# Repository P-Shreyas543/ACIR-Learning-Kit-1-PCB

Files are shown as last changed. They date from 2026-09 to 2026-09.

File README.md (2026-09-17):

# ACIR Learning Kits - Characterization & Experimentation Platform

**Decibels Lab Pvt Ltd**  
*Project Repository: [ACIR-Learning-Kit-1-PCB](https://github.com/P-Shreyas543/ACIR-Learning-Kit-1-PCB)*  
*Revision: v2.1 | Date: 2026-09-17*

---

## Overview

The **ACIR Learning Kits** are specialized, production-ready hardware characterization platforms designed for educational, research, and laboratory electrochemical impedance spectroscopy (EIS) and AC internal resistance (ACIR) testing of 18650 lithium-ion cells.

The repository contains two distinct learning kits:

### Learning Kit 1: Baseline Cell & Pack Topology Kit
1. **1S 1P Baseline Cell**: Single 18650 cell baseline ACIR characterization.
2. **1S 4P Parallel Pack**: Four-cell parallel module for current-sharing, contact resistance, and parallel cell mismatch studies.
3. **4S 1P Series String**: Four-cell series string for cumulative pack impedance and inter-cell busbar resistance.

### Learning Kit 2: Track Resistance & Interconnect Impedance Kit
1. **PCB Track Resistance Module**:
   - 3 calibrated test tracks with identical $6.0\text{ mm}$ width and varying lengths ($104.4\text{ mm}$, $58.0\text{ mm}$, $36.4\text{ mm}$).
   - Mirrored symmetrically on both copper layers (`F.Cu` and `B.Cu`).
   - Densely stitched with regular via matrices ($0.8\text{ mm}$ diameter, $0.4\text{ mm}$ drill).
   - Dedicated Kelvin test point probes: `P1` & `P2` (Track 1), `P3` & `P4` (Track 2), `P5` & `P6` (Track 3).
2. **4S 1P - (I) Module (Differential Cell ACIR Experiment)**:
   - 4 series cells (`BT2`, `BT3`, `BT4`, `BT5`) with uniform, ultra-low resistance interconnect buses ($8.0\text{ mm}$ 2-layer with dense via arrays).
   - Pack terminals: `B +ve` (BT2) and `B -ve` (BT5).
   - Students insert cells with *different* known ACIR values to observe that total pack ACIR is dominated by the sum of individual cell ACIRs when bus resistances are identical and negligible.
3. **4S 1P - (II) Module (Varying Interconnect Impedance Experiment)**:
   - 4 series cells (`BT6`, `BT7`, `BT8`, `BT9`) with deliberately *varying* interconnect track resistances:
     - **Link 1** (`BT6` $\leftrightarrow$ `BT7`): Ultra-wide $10.0\text{ mm}$ 2-layer bus with dense via matrix ($\approx 0.5\text{ m}\Omega$).
     - **Link 2** (`BT7` $\leftrightarrow$ `BT8`): Medium $3.0\text{ mm}$ single-layer trace ($\approx 3.0\text{ m}\Omega$).
     - **Link 3** (`BT8` $\leftrightarrow$ `BT9`): Narrow $0.8\text{ mm}$ single-layer trace ($\approx 10.0\text{ m}\Omega$).
   - Pack terminals: `B +ve` (BT6) and `B -ve` (BT9).
   - Students insert cells with *identical* ACIR values to demonstrate how interconnect trace impedance directly inflates total battery pack ACIR.

---

## Repository Structure

```
c:/Users/Shreyas/Documents/ACIR_PCB/
├── README.md                                  # Workspace Platform Documentation
├── .gitignore                                 # Git Ignore Configuration
├── ACIR-Learning-Kit-1-PCB/                   # Learning Kit 1 Project Directory
│   ├── ACIR-Learning-Kit-1-PCB.kicad_pro      # KiCad 10 Project File
│   ├── ACIR-Learning-Kit-1-PCB.kicad_pcb      # 2-Layer PCB Layout File
│   ├── ACIR-Learning-Kit-1-PCB.kicad_sch      # Complete Schematic Design
│   ├── ACIR-Learning-Kit-1-PCB.kicad_prl      # User Settings & Display Cache
│   ├── ACIR-Learning-Kit-1-PCB_BOM.csv        # Bill of Materials
│   ├── ACIR-Learning-Kit-1-PCB_LAYOUT.pdf     # Vector Layout Drawing
│   ├── ACIR-Learning-Kit-1-PCB_SCH.pdf        # Vector Schematic Drawing
│   ├── ACIR-Learning-Kit-1-PCB-drc.rpt        # DRC Verification Report (0 violations)
│   ├── ACIR-Learning-Kit-1-PCB-erc.rpt        # ERC Verification Report (0 errors)
│   ├── fp-lib-table                           # Footprint Library Table
│   ├── footprints.pretty/                     # Project Footprint Library
│   ├── gerbers/                               # RS-274X Gerbers & Drill Files
│   └── production/                            # JLCPCB Fabrication Deliverables
│       ├── ACIR-Learning-Kit-1-PCB_gerbers.zip# Complete Fabrication Archive
│       ├── ACIR-Learning-Kit-1-PCB_LAYOUT.pdf # Layout Drawing PDF
│       ├── ACIR-Learning-Kit-1-PCB_SCH.pdf    # Schematic Drawing PDF
│       ├── bom.csv                            # Component BOM
│       ├── positions.csv                      # Centroid Component Placement
│       └── netlist.ipc                        # IPC-D-356 Test Netlist
│
└── ACIR-Learning-Kit-2-PCB/                   # Learning Kit 2 Project Directory
    ├── ACIR-Learning-Kit-2-PCB.kicad_pro      # KiCad 10 Project File
    ├── ACIR-Learning-Kit-2-PCB.kicad_pcb      # 2-Layer PCB Layout File
    ├── ACIR-Learning-Kit-2-PCB.kicad_sch      # Complete Schematic Design
    ├── ACIR-Learning-Kit-2-PCB.kicad_prl      # User Settings & Display Cache
    ├── ACIR-Learning-Kit-2-PCB_BOM.csv        # Bill of Materials
    ├── ACIR-Learning-Kit-2-PCB_LAYOUT.pdf     # Vector Layout Drawing
    ├── ACIR-Learning-Kit-2-PCB_SCH.pdf        # Vector Schematic Drawing
    ├── ACIR-Learning-Kit-2-PCB-drc.rpt        # DRC Verification Report (0 violations)
    ├── ACIR-Learning-Kit-2-PCB-erc.rpt        # ERC Verification Report (0 errors)
    ├── kit2_render_top.png                    # Photorealistic 3D Top Render
    ├── kit2_render_bottom.png                 # Photorealistic 3D Bottom Render
    ├── fp-lib-table                           # Footprint Library Table
    ├── footprints.pretty/                     # Project Footprint Library
    ├── gerbers/                               # RS-274X Gerbers & Drill Files
    └── production/                            # JLCPCB Fabrication Deliverables
        ├── ACIR-Learning-Kit-2-PCB_gerbers.zip# Complete Fabrication Archive
        ├── ACIR-Learning-Kit-2-PCB_LAYOUT.pdf # Layout Drawing PDF
        ├── ACIR-Learning-Kit-2-PCB_SCH.pdf    # Schematic Drawing PDF
        ├── bom.csv                            # Component BOM
        ├── positions.csv                      # Centroid Component Placement
        └── netlist.ipc                        # IPC-D-356 Test Netlist
```

---

## PCB Specifications (Both Kits)

- **Dimensions**: $297.0\text{ mm} \times 210.0\text{ mm}$ (Standard A4 Landscape)
- **Layer Count**: 2 Layers ($1\text{ oz}$ / $35\,\mu\text{m}$ copper per layer)
- **Board Thickness**: $1.6\text{ mm}$ FR-4
- **Surface Finish**: HASL / ENIG compatible
- **Fabrication Compliance**: Verified 100% compliant with JLCPCB 2-layer fabrication capabilities:
  - **DRC**: **0 violations**, **0 unconnected pads**
  - **ERC**: **0 violations**, **0 errors**, **0 warnings**

---

## Design Team
- **Ashutosh Raj**
- **Shreyas P**
- **Suraj S D**

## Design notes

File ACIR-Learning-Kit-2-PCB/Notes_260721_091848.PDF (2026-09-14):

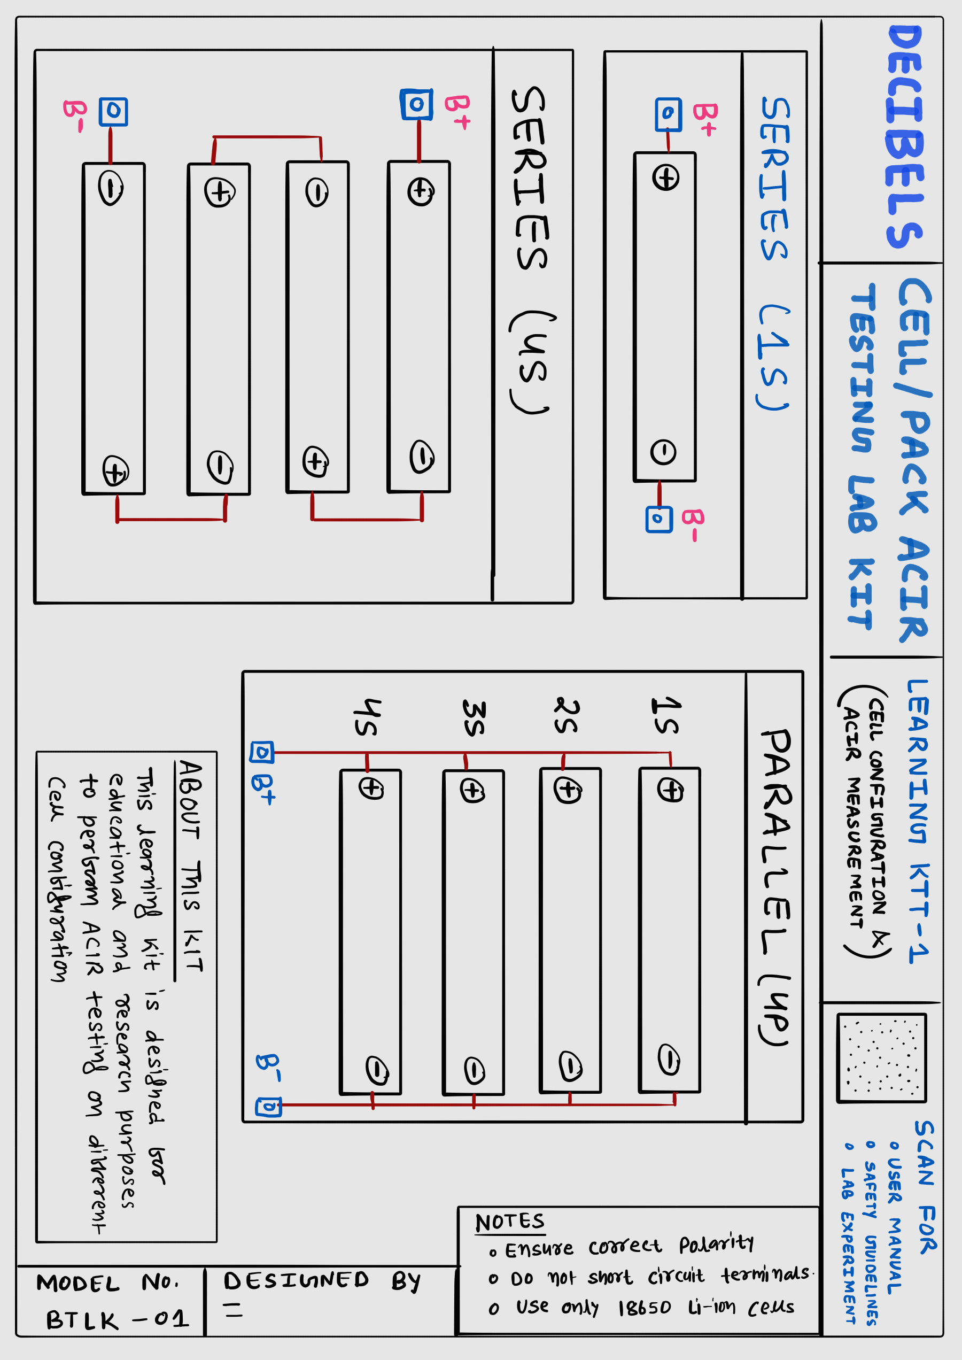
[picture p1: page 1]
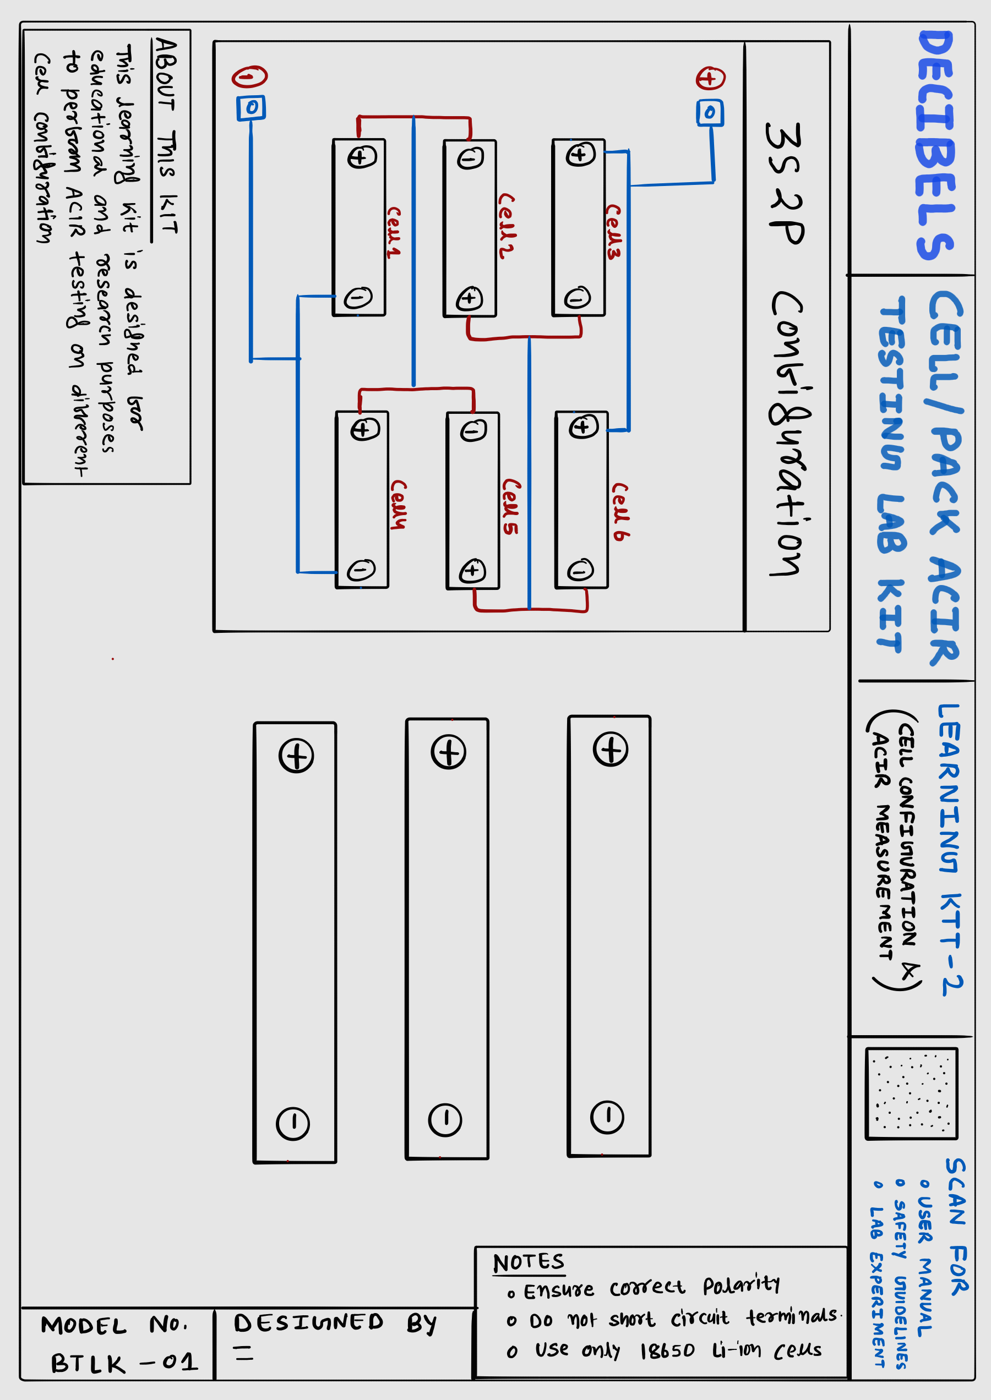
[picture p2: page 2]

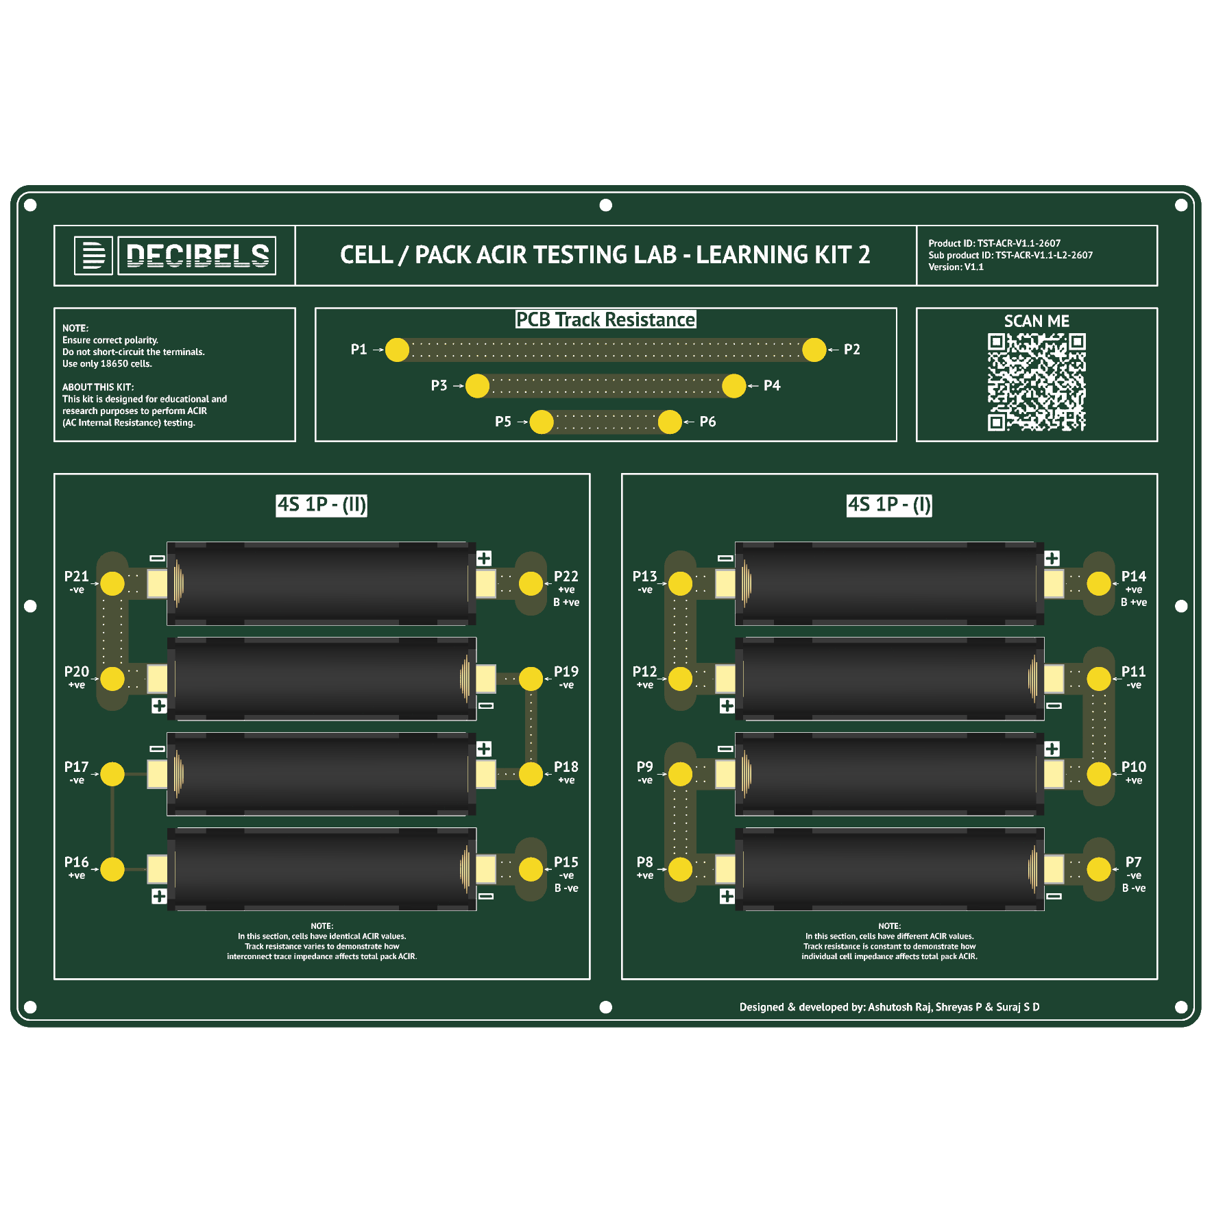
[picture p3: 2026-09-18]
ACIR-Learning-Kit-2-PCB/kit2_render_top.png

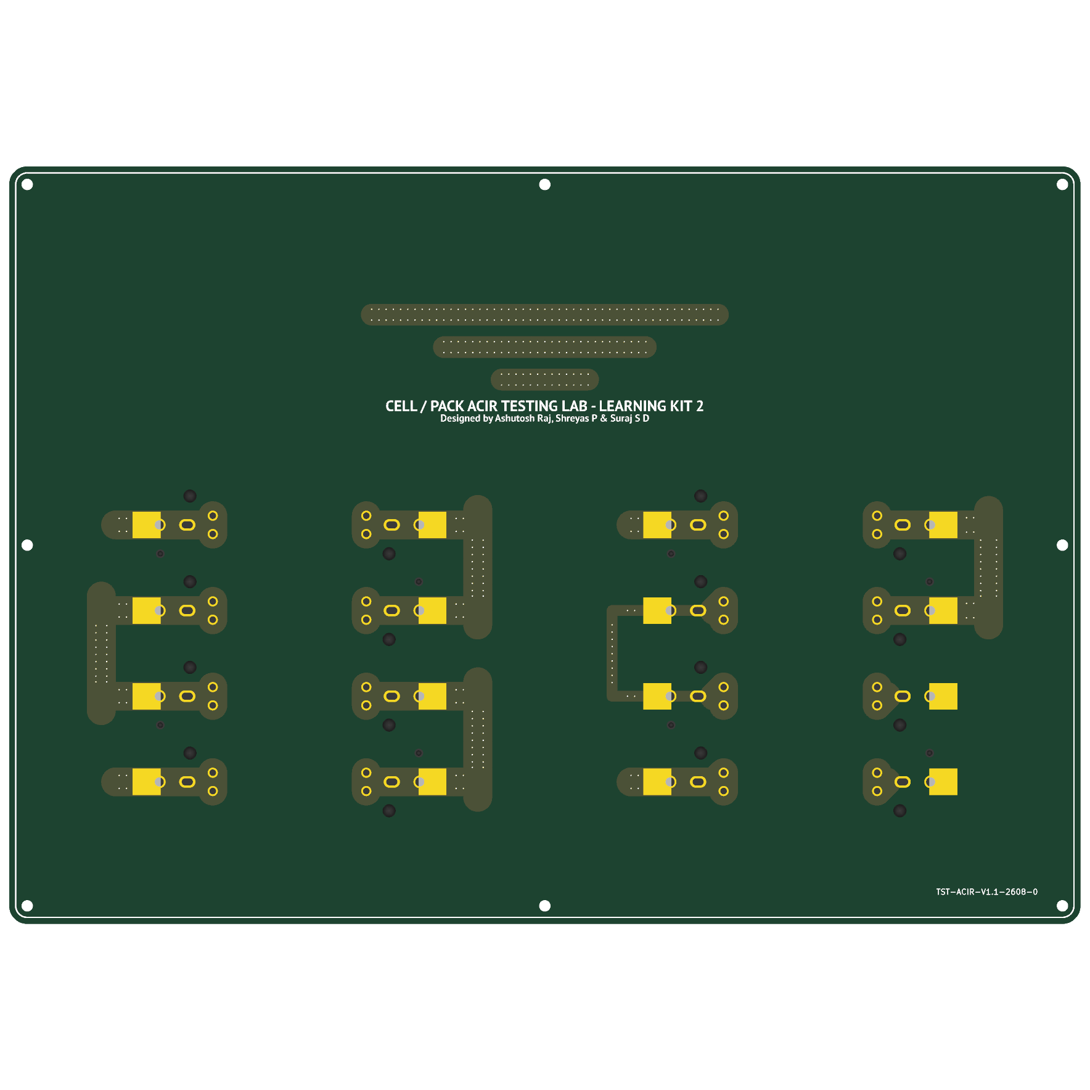
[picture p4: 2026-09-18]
ACIR-Learning-Kit-2-PCB/kit2_render_bottom.png

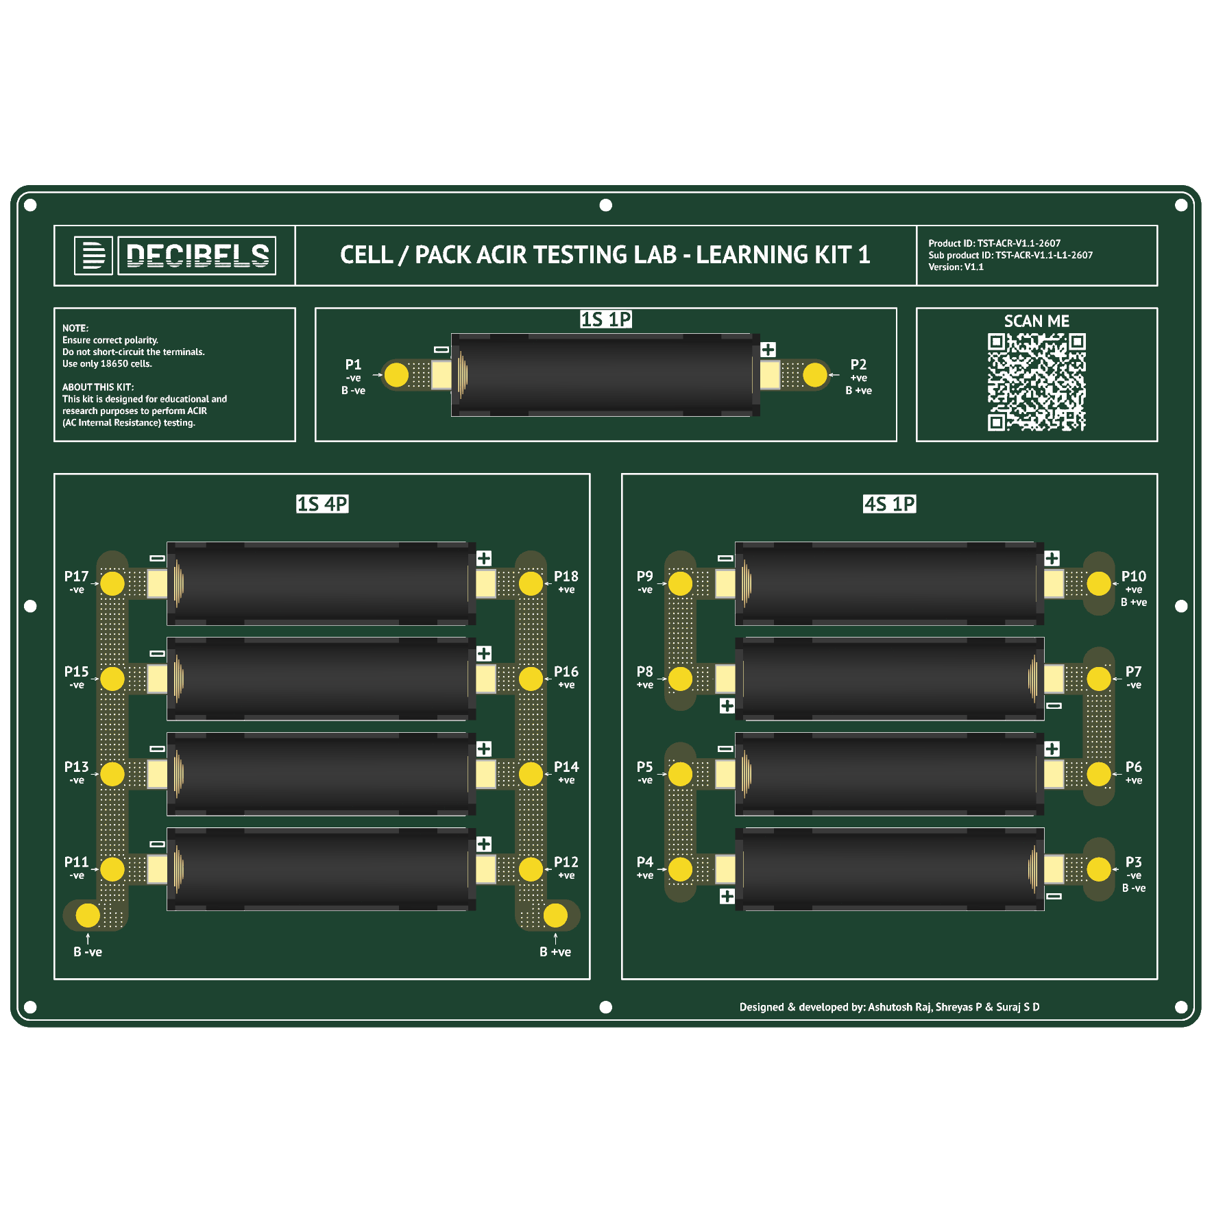
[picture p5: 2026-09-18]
ACIR-Learning-Kit-1-PCB/kit1_render_top.png

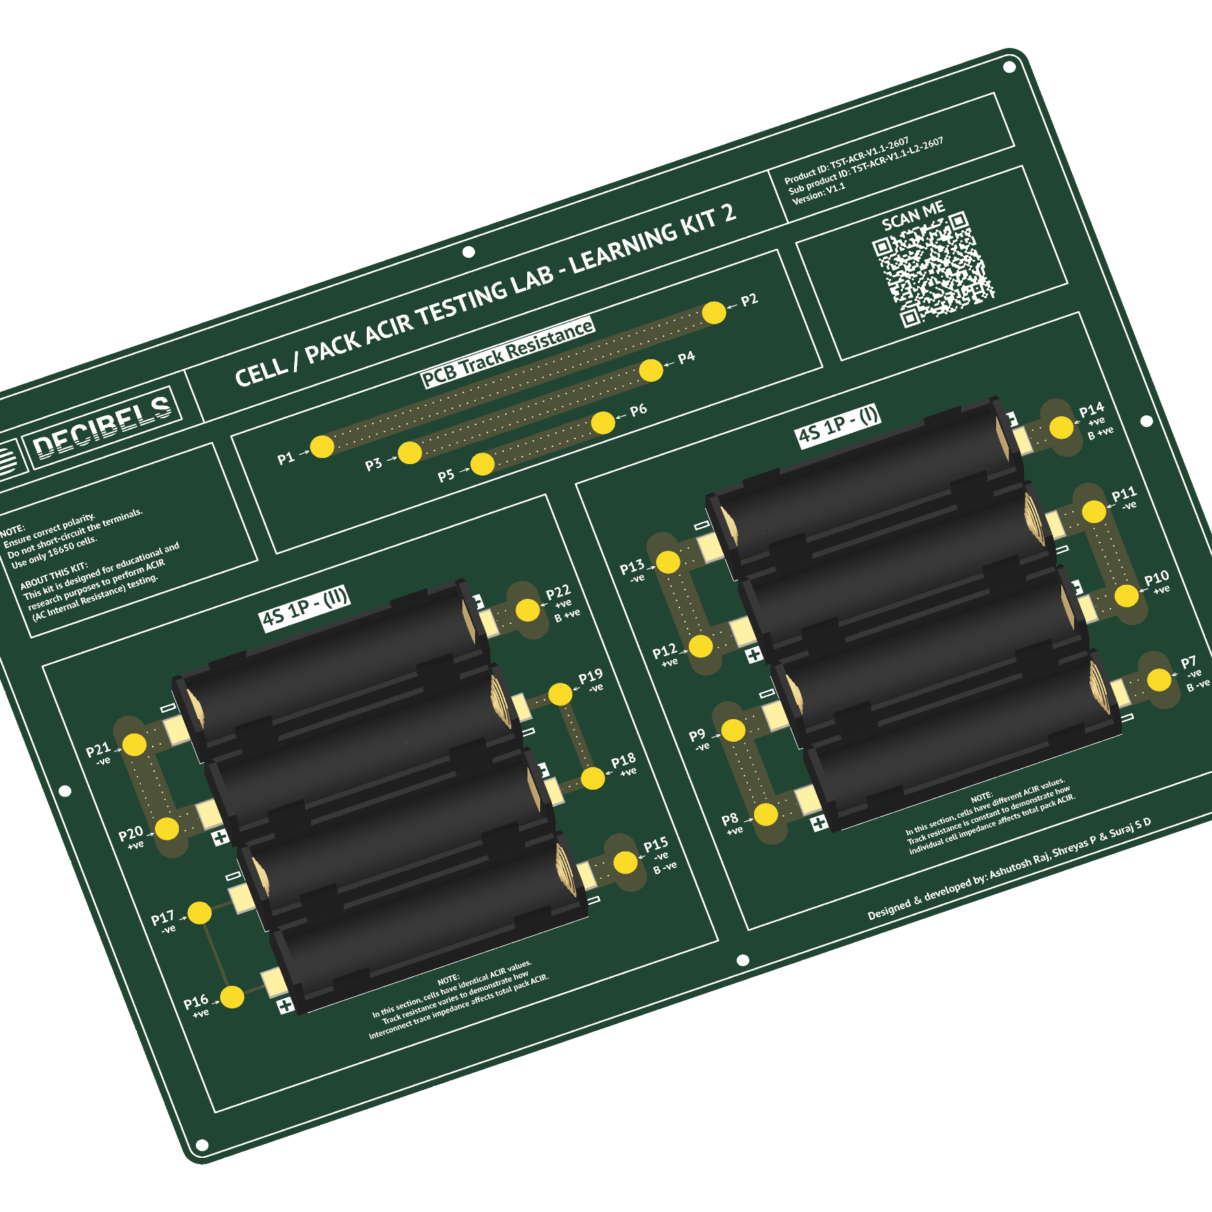
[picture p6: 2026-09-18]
ACIR-Learning-Kit-2-PCB/kit2_render_isometric.png

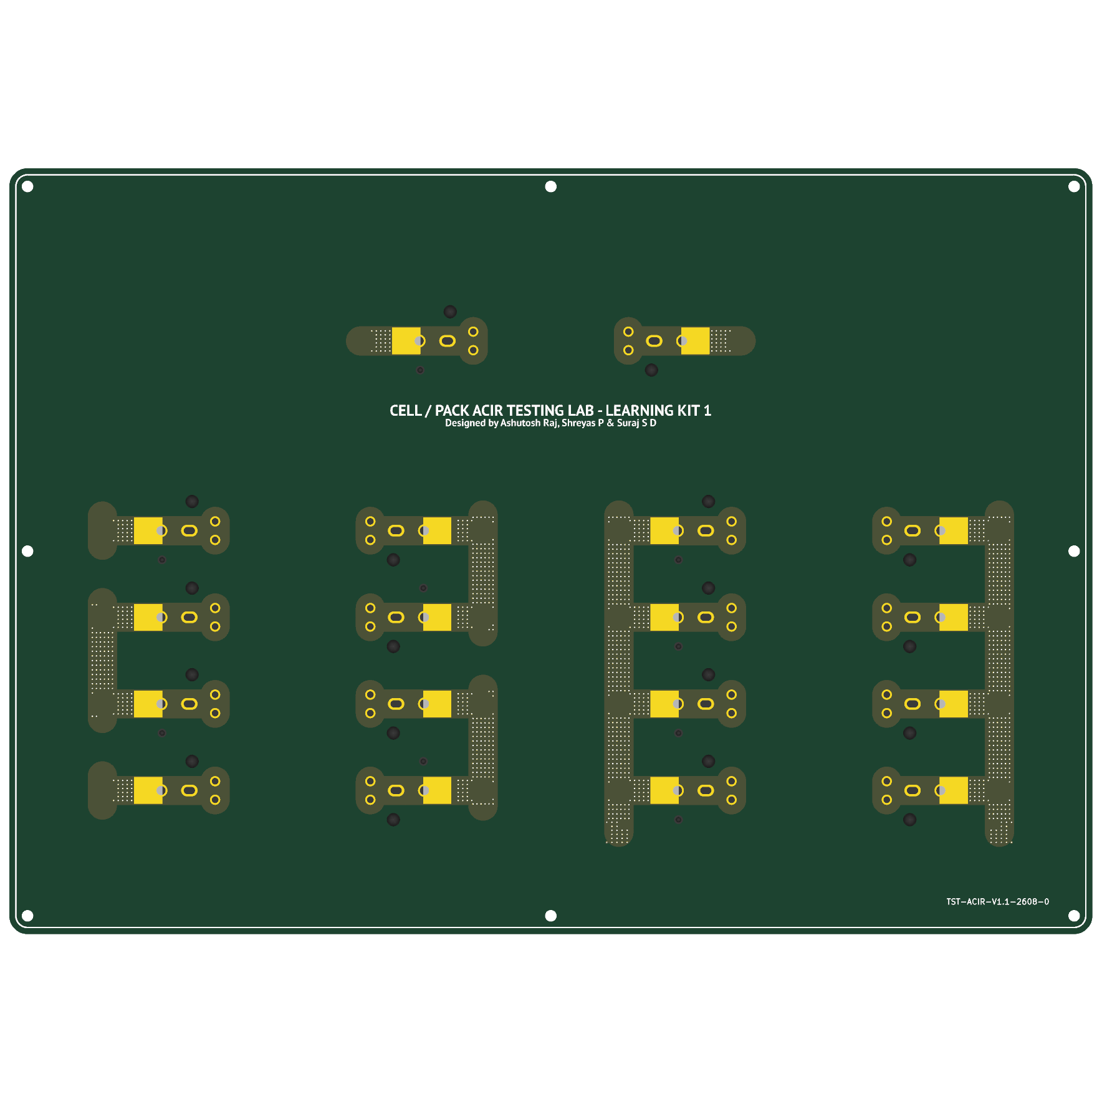
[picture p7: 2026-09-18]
ACIR-Learning-Kit-1-PCB/kit1_render_bottom.png

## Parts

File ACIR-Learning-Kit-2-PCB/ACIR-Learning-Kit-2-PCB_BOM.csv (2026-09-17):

Refs | Value | Footprint | Qty | DNP
BT2 | BH-18650-B5BA008 | footprints:BH18650B1BA002 | 1
BT3 | BH-18650-B5BA008 | footprints:BH18650B1BA002 | 1
BT4 | BH-18650-B5BA008 | footprints:BH18650B1BA002 | 1
BT5 | BH-18650-B5BA008 | footprints:BH18650B1BA002 | 1
BT6 | BH-18650-B5BA008 | footprints:BH18650B1BA002 | 1
BT7 | BH-18650-B5BA008 | footprints:BH18650B1BA002 | 1
BT8 | BH-18650-B5BA008 | footprints:BH18650B1BA002 | 1
BT9 | BH-18650-B5BA008 | footprints:BH18650B1BA002 | 1

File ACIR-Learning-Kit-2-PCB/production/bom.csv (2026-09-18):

Designator | Footprint | Quantity | Value | LCSC Part #
BT2, BT3, BT4, BT5, BT6, BT7, BT8, BT9 | BH18650B1BA002 | 8 | BH-18650-B5BA008

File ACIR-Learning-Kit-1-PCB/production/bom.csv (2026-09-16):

Designator | Footprint | Quantity | Value | LCSC Part #
BT1, BT2, BT3, BT4, BT5, BT6, BT7, BT8, BT9 | BH18650B1BA002 | 9 | BH-18650-B5BA008

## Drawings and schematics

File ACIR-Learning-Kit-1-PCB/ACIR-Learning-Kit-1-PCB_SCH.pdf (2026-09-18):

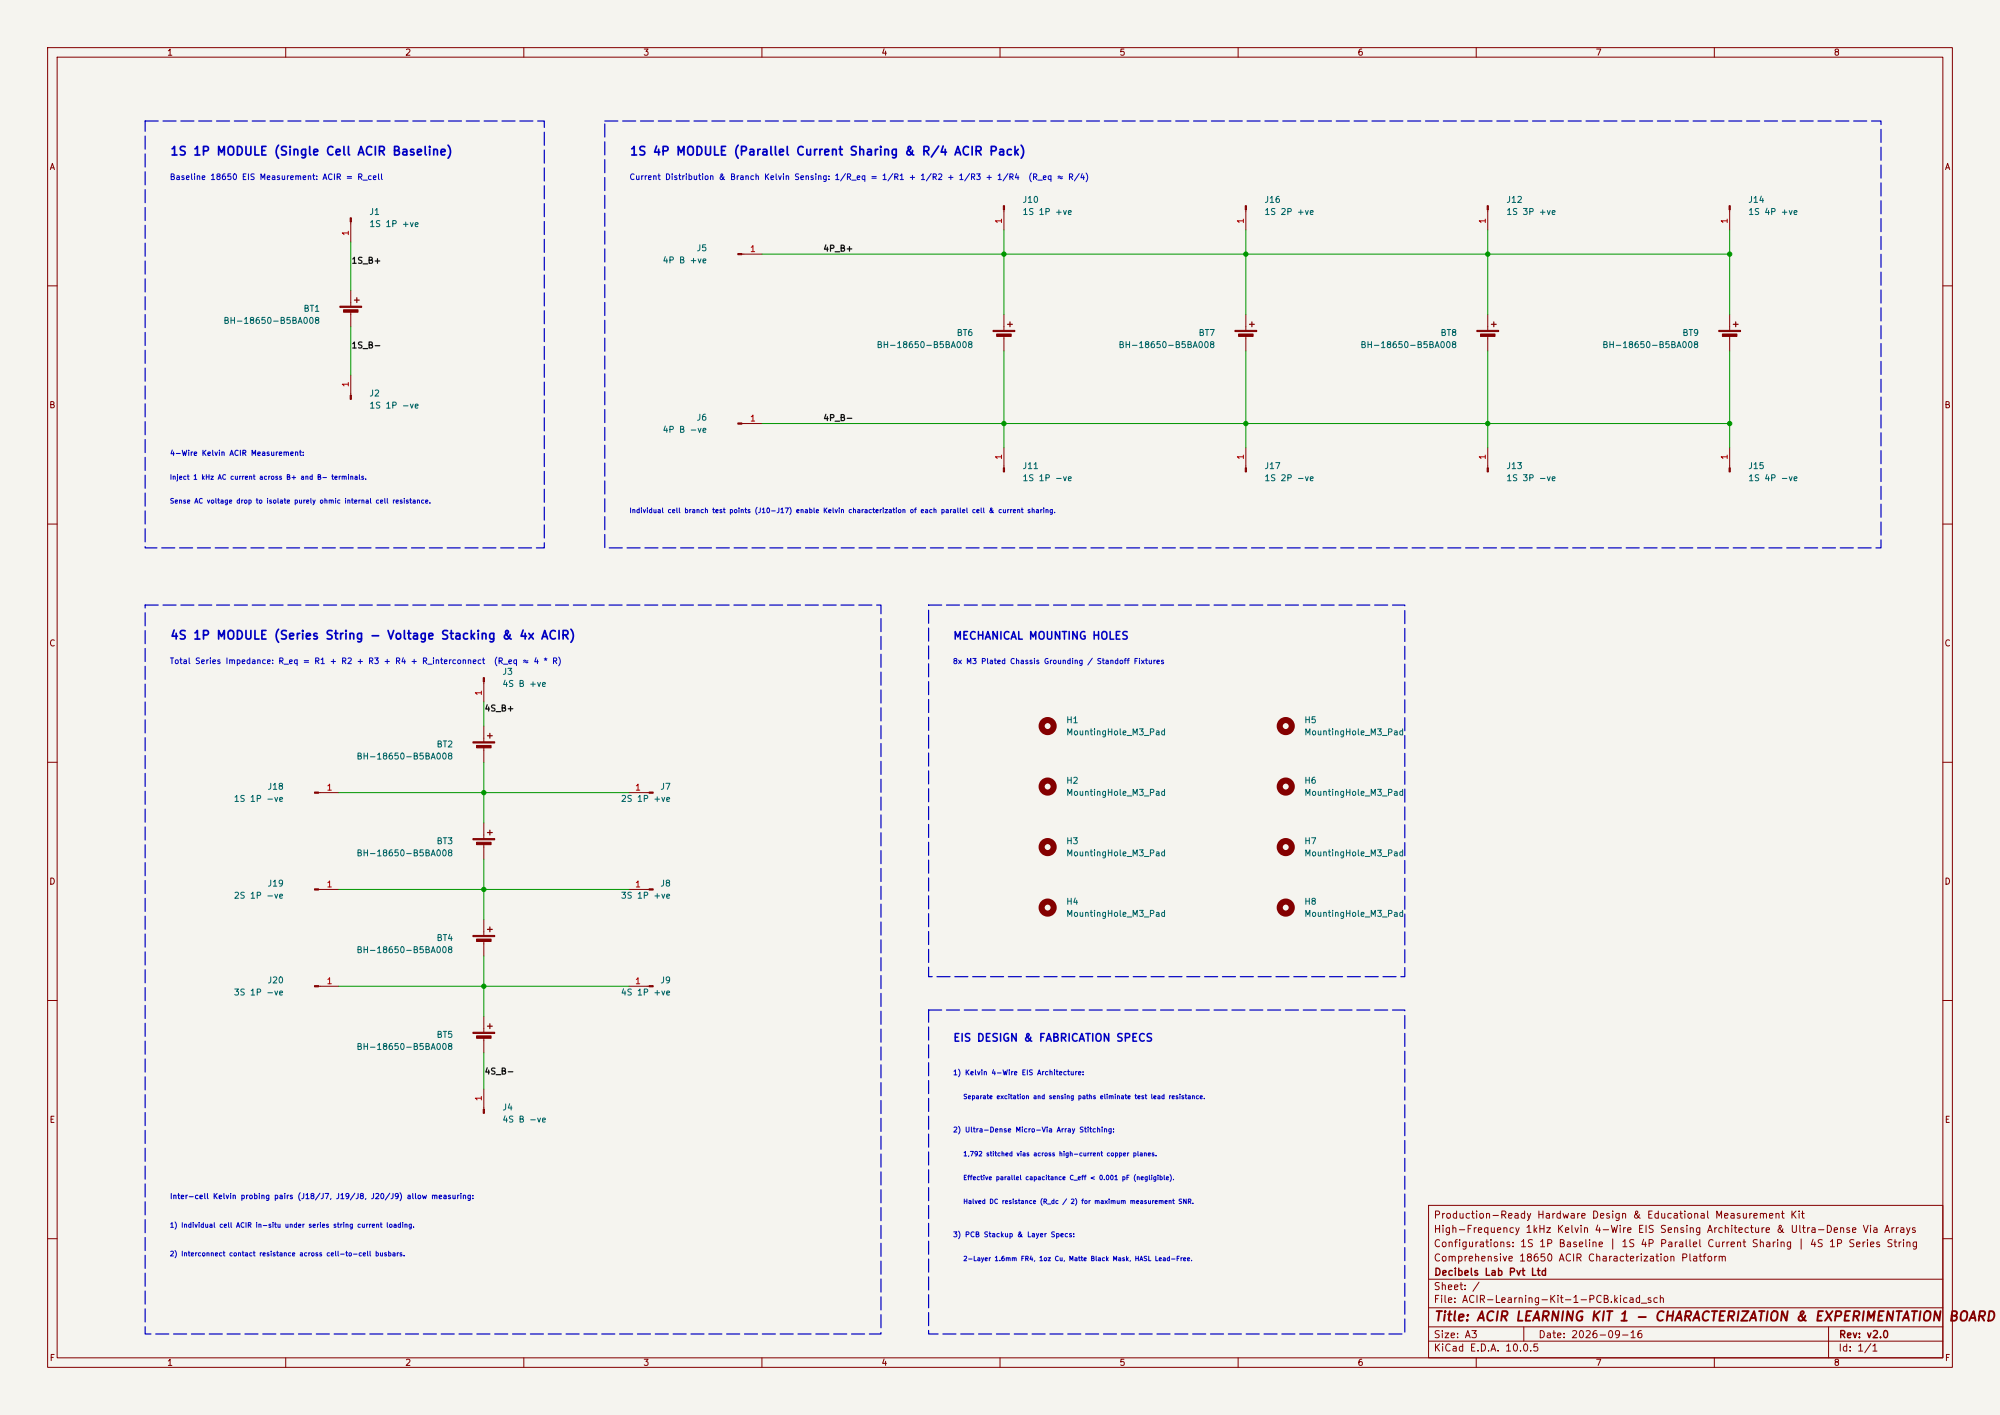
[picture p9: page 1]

4-Wire Kelvin ACIR Measurement: Baseline 18650 EIS Measurement: ACIR = R_cell 1S 1P MODULE (Single Cell ACIR Baseline)

1S 4P MODULE (Parallel Current Sharing & R/4 ACIR Pack)

Current Distribution & Branch Kelvin Sensing: 1/R_eq = 1/R1 + 1/R2 + 1/R3 + 1/R4 (R_eq ≈ R/4)

Total Series Impedance: R_eq = R1 + R2 + R3 + R4 + R_interconnect (R_eq ≈ 4 * R) Sense AC voltage drop to isolate purely ohmic internal cell resistance.

Individual cell branch test points (J10-J17) enable Kelvin characterization of each parallel cell & current sharing.

4S 1P MODULE (Series String - Voltage Stacking & 4x ACIR)

EIS DESIGN & FABRICATION SPECS

1) Kelvin 4-Wire EIS Architecture: 3) PCB Stackup & Layer Specs: 2-Layer 1.6mm FR4, 1oz Cu, Matte Black Mask, HASL Lead-Free. Separate excitation and sensing paths eliminate test lead resistance.

2) Ultra-Dense Micro-Via Array Stitching:

1,792 stitched vias across high-current copper planes. Halved DC resistance (R_dc / 2) for maximum measurement SNR. Effective parallel capacitance C_eff < 0.001 pF (negligible).

Inter-cell Kelvin probing pairs (J18/J7, J19/J8, J20/J9) allow measuring:

Production-Ready Hardware Design & Educational Measurement Kit
High-Frequency 1kHz Kelvin 4-Wire EIS Sensing Architecture & Ultra-Dense Via Arrays
Configurations: 1S 1P Baseline | 1S 4P Parallel Current Sharing | 4S 1P Series String
Comprehensive 18650 ACIR Characterization Platform
Decibels Lab Pvt Ltd
Sheet: /
File: ACIR-Learning-Kit-1-PCB.kicad_sch
Title: ACIR LEARNING KIT 1 - CHARACTERIZATION & EXPERIMENTATION BOARD

2) Interconnect contact resistance across cell-to-cell busbars. 1) Individual cell ACIR in-situ under series string current loading.

Size: A3 | Rev: v2.0 | F Date: 2026-09-16
KiCad E.D.A. 10.0.5 | Id: 1/1

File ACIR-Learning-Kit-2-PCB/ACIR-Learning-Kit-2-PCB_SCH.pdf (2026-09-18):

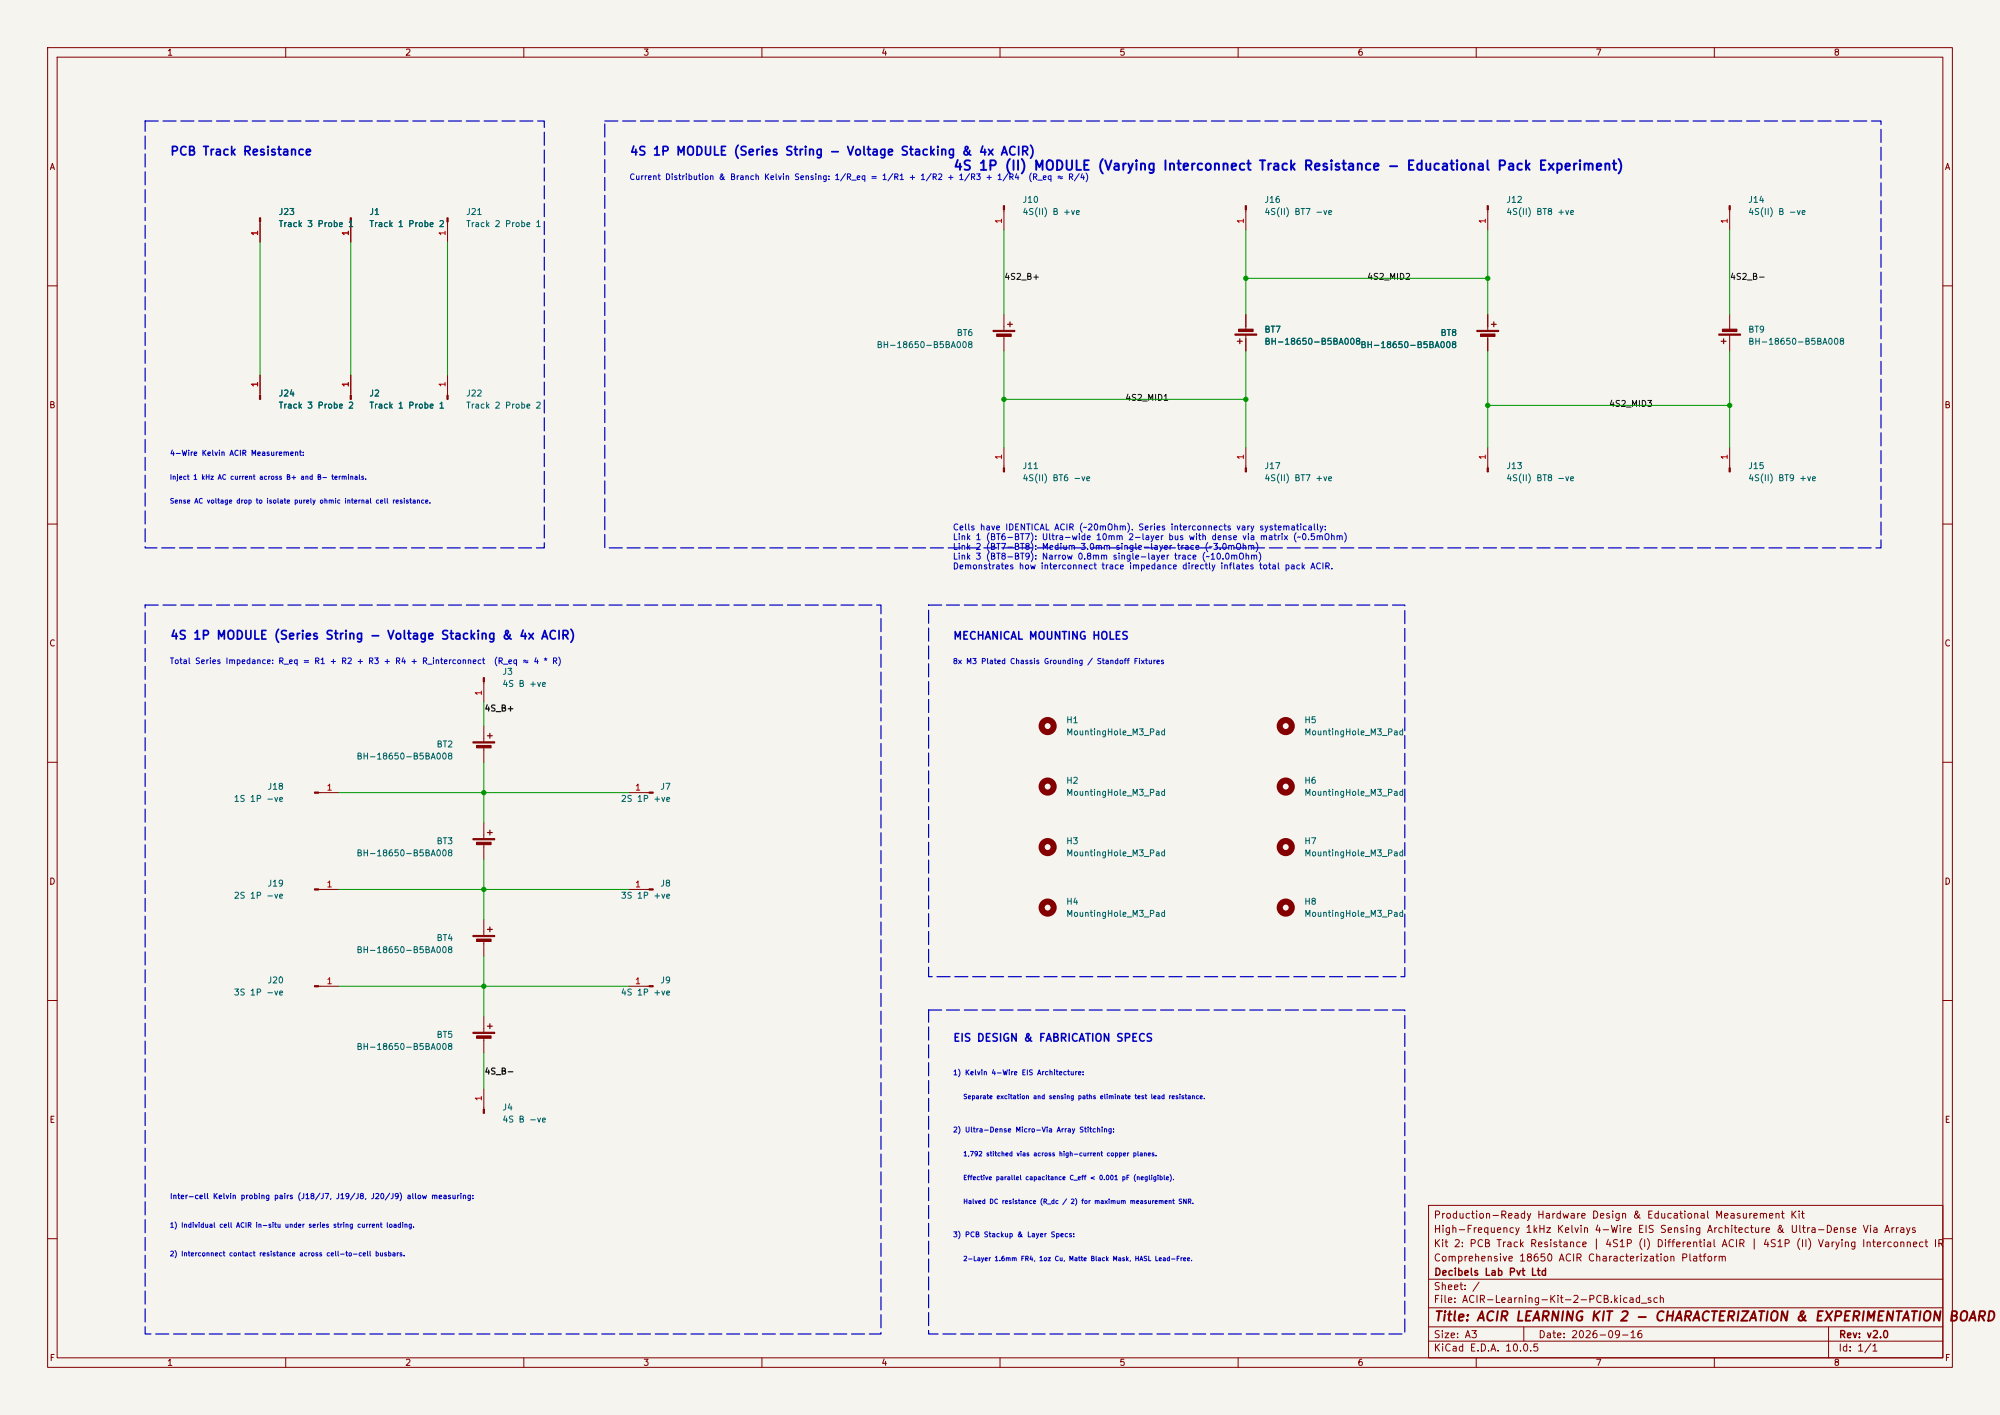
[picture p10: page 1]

4S 1P (II) MODULE (Varying Interconnect Track Resistance - Educational Pack Experiment)

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

Inject 1 kHz AC current across B+ and B- terminals. 4S 1P MODULE (Series String - Voltage Stacking & 4x ACIR)

Sense AC voltage drop to isolate purely ohmic internal cell resistance.

Cells have IDENTICAL ACIR (~20mOhm). Series interconnects vary systematically: Link 1 (BT6-BT7): Ultra-wide 10mm 2-layer bus with dense via matrix (~0.5mOhm) Link 2 (BT7-BT8): Medium 3.0mm single-layer trace (~3.0mOhm) Link 3 (BT8-BT9): Narrow 0.8mm single-layer trace (~10.0mOhm) Demonstrates how interconnect trace impedance directly inflates total pack ACIR. MECHANICAL MOUNTING HOLES

Production-Ready Hardware Design & Educational Measurement Kit H4MountingHole_M3_Pad

EIS DESIGN & FABRICATION SPECS

1) Kelvin 4-Wire EIS Architecture:

Inter-cell Kelvin probing pairs (J18/J7, J19/J8, J20/J9) allow measuring:

1) Individual cell ACIR in-situ under series string current loading.

High-Frequency 1kHz Kelvin 4-Wire EIS Sensing Architecture & Ultra-Dense Via Arrays
Kit 2: PCB Track Resistance | 4S1P (I) Differential ACIR | 4S1P (II) Varying Interconnect IR
Comprehensive 18650 ACIR Characterization Platform
Decibels Lab Pvt Ltd
Sheet: /
File: ACIR-Learning-Kit-2-PCB.kicad_sch
Title: ACIR LEARNING KIT 2 - CHARACTERIZATION & EXPERIMENTATION BOARD

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

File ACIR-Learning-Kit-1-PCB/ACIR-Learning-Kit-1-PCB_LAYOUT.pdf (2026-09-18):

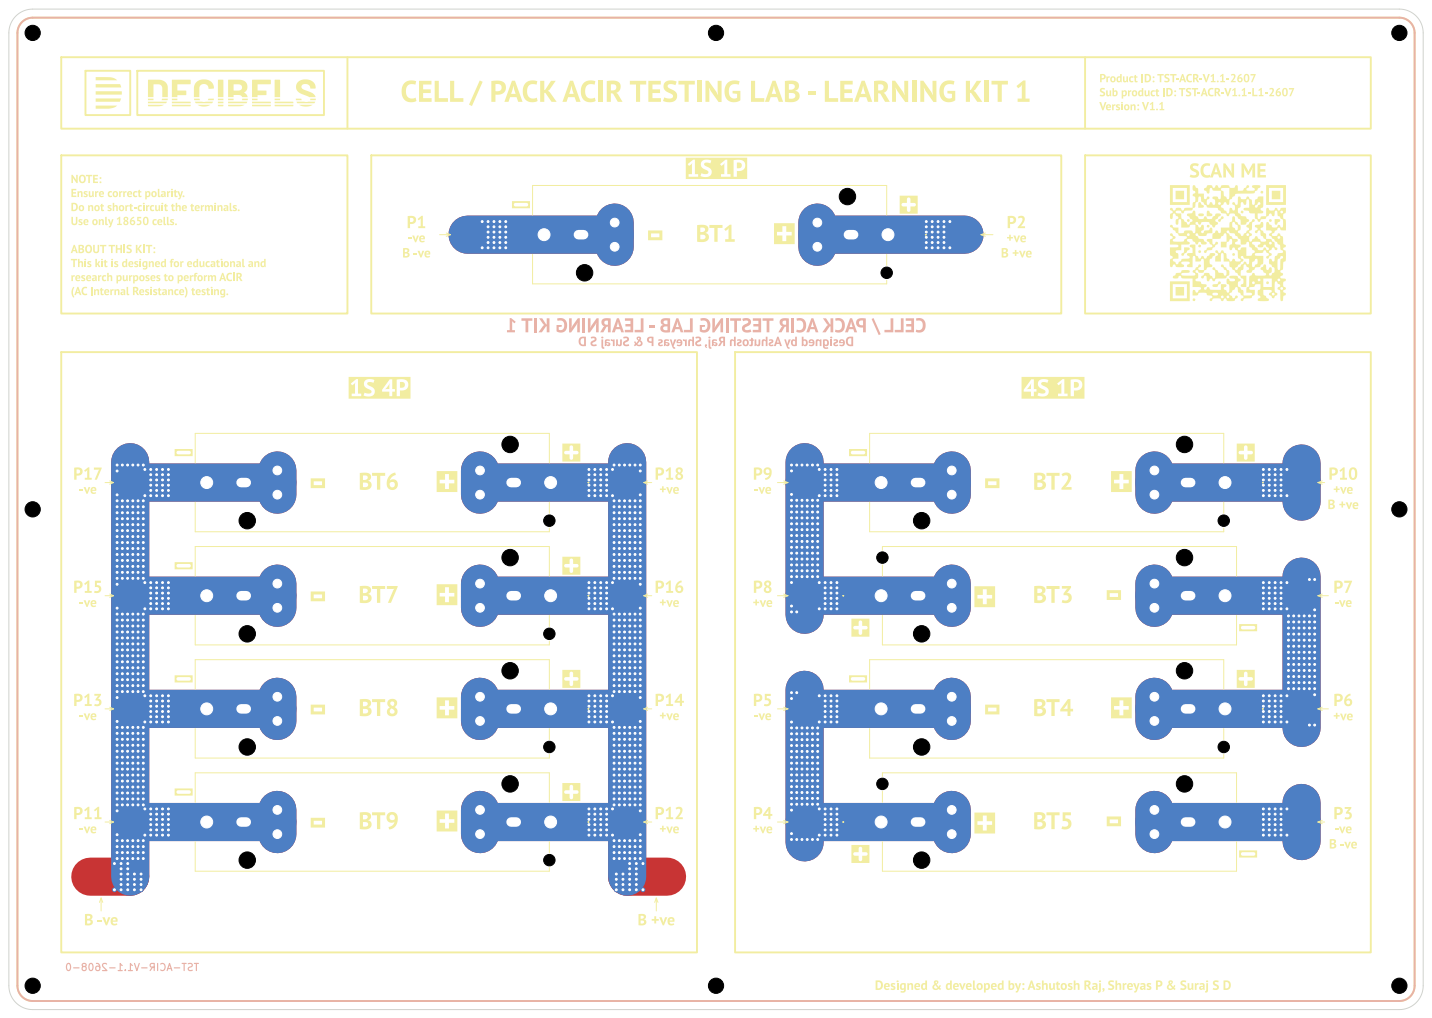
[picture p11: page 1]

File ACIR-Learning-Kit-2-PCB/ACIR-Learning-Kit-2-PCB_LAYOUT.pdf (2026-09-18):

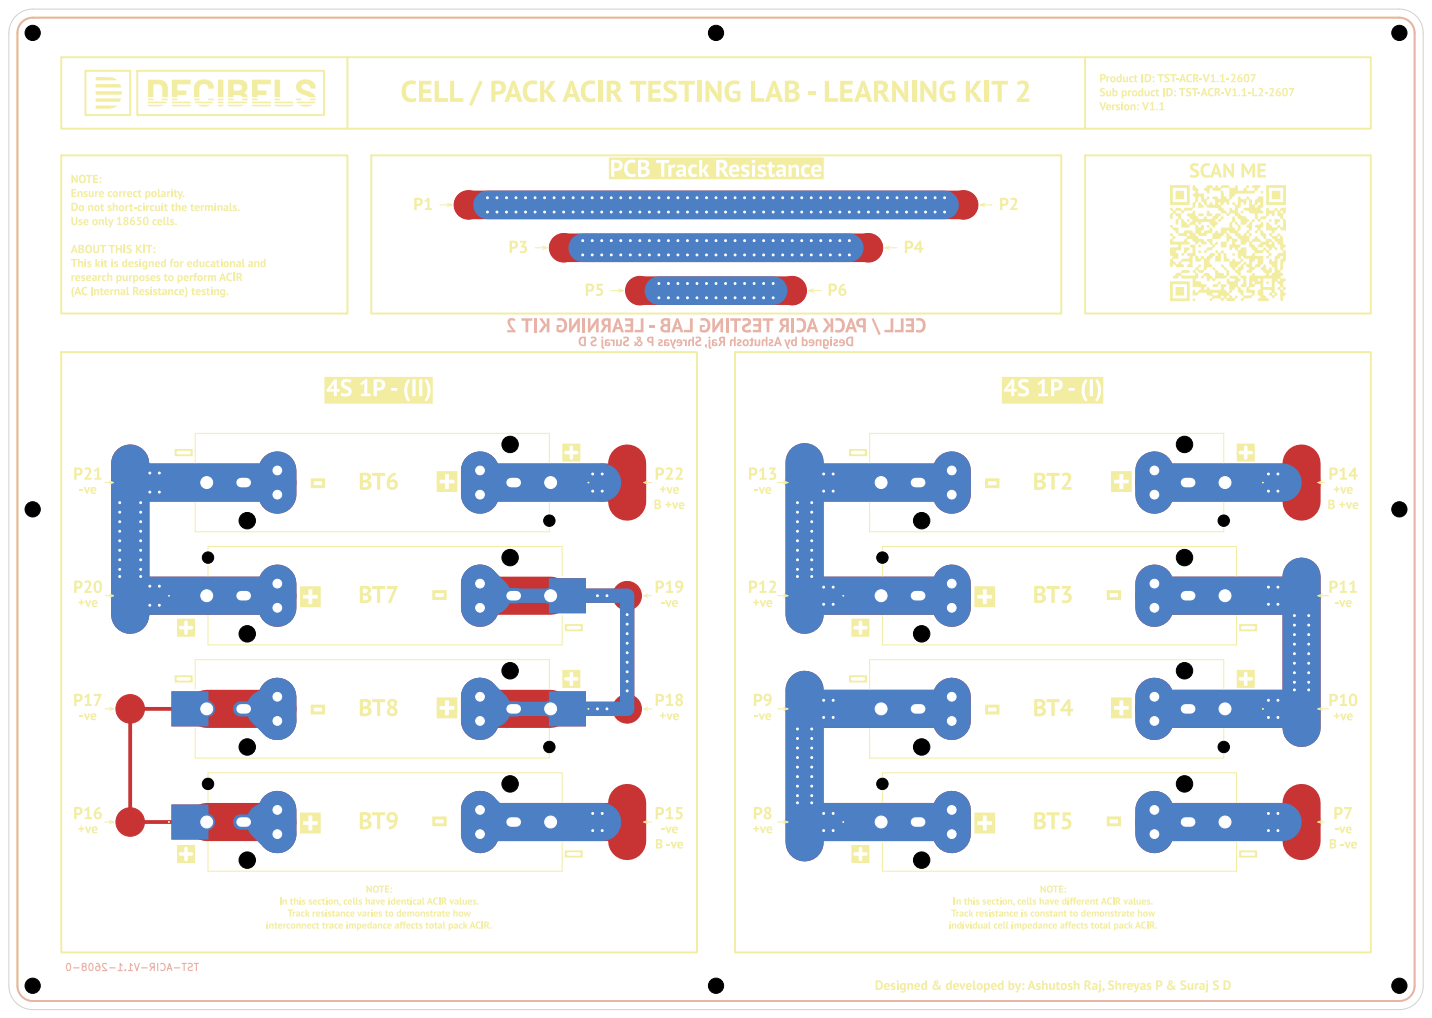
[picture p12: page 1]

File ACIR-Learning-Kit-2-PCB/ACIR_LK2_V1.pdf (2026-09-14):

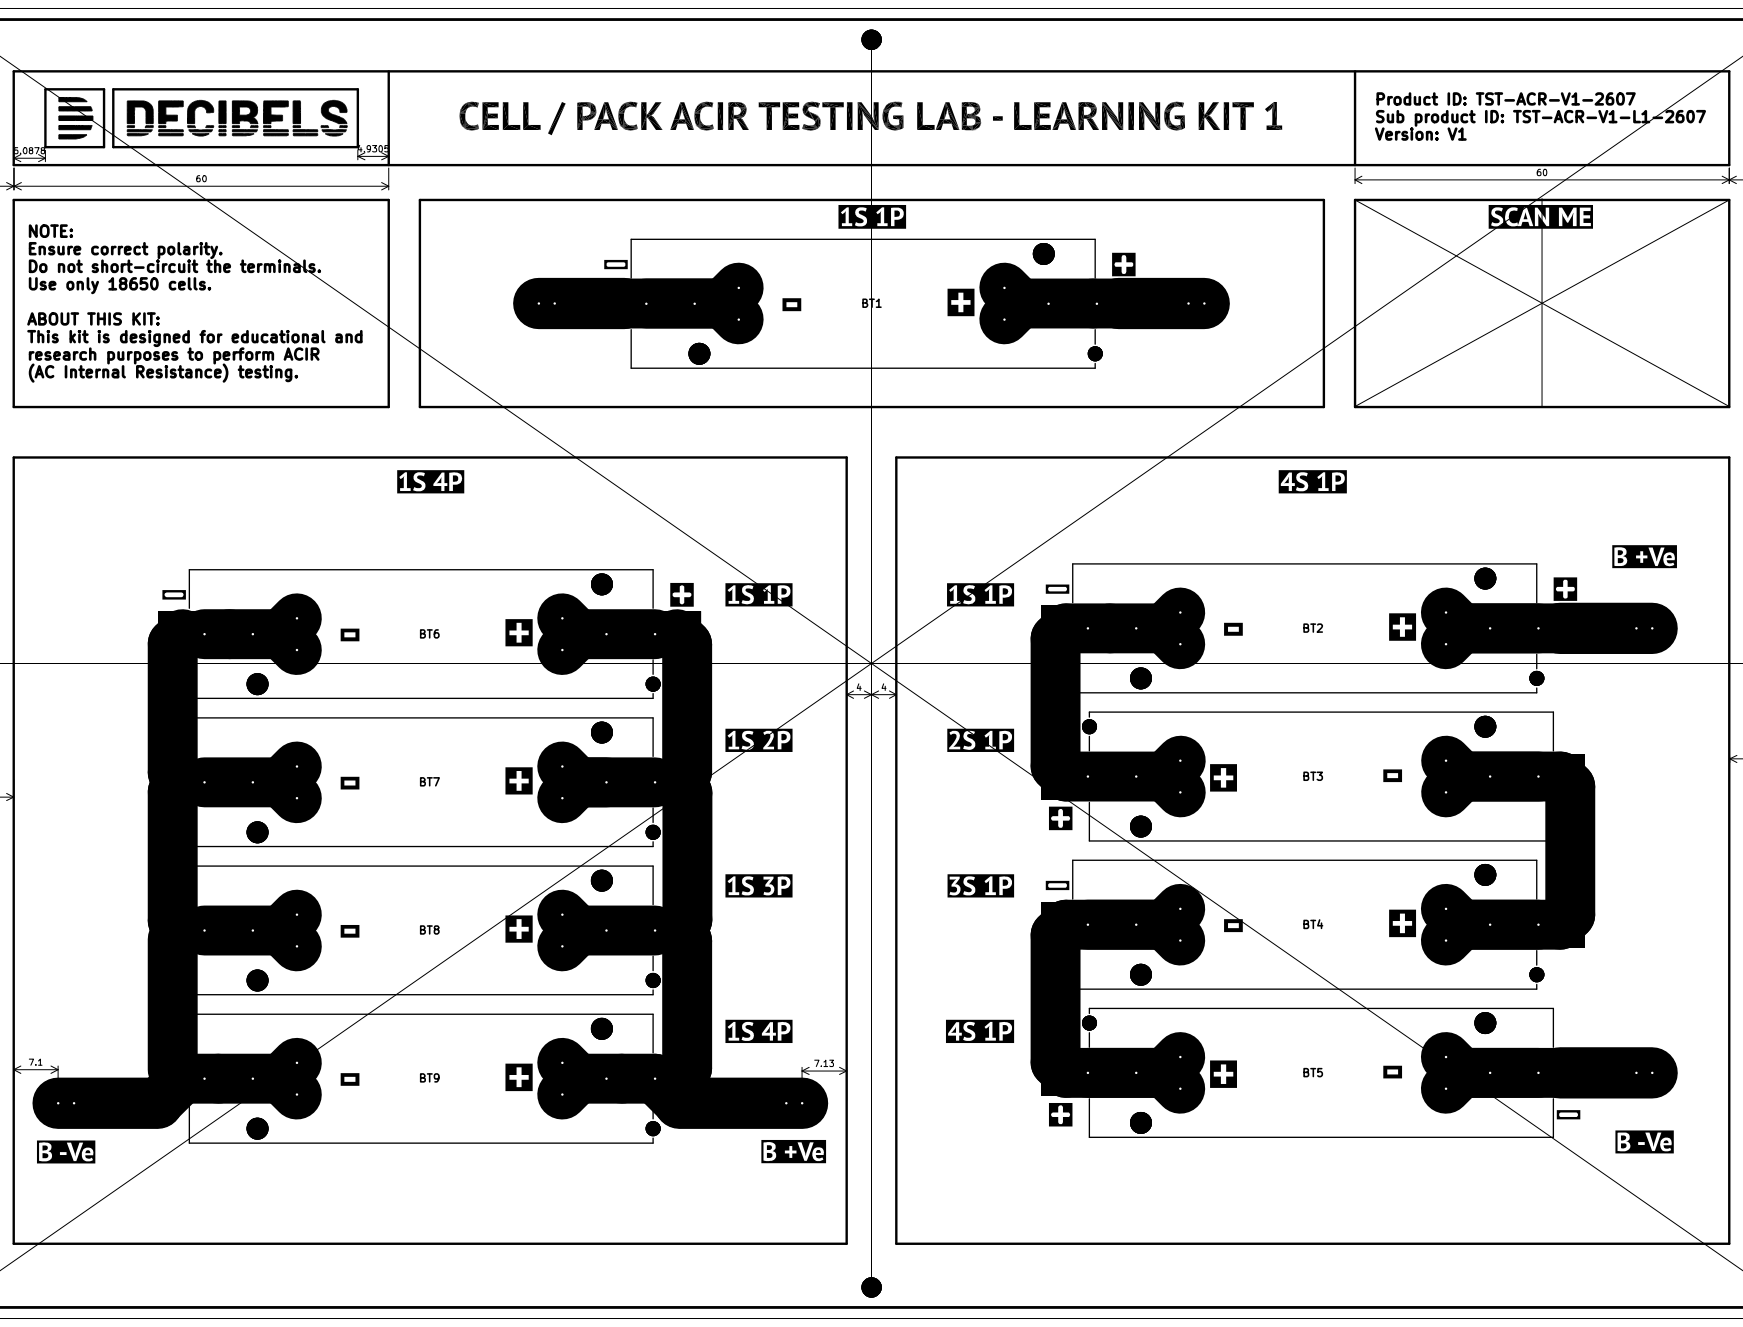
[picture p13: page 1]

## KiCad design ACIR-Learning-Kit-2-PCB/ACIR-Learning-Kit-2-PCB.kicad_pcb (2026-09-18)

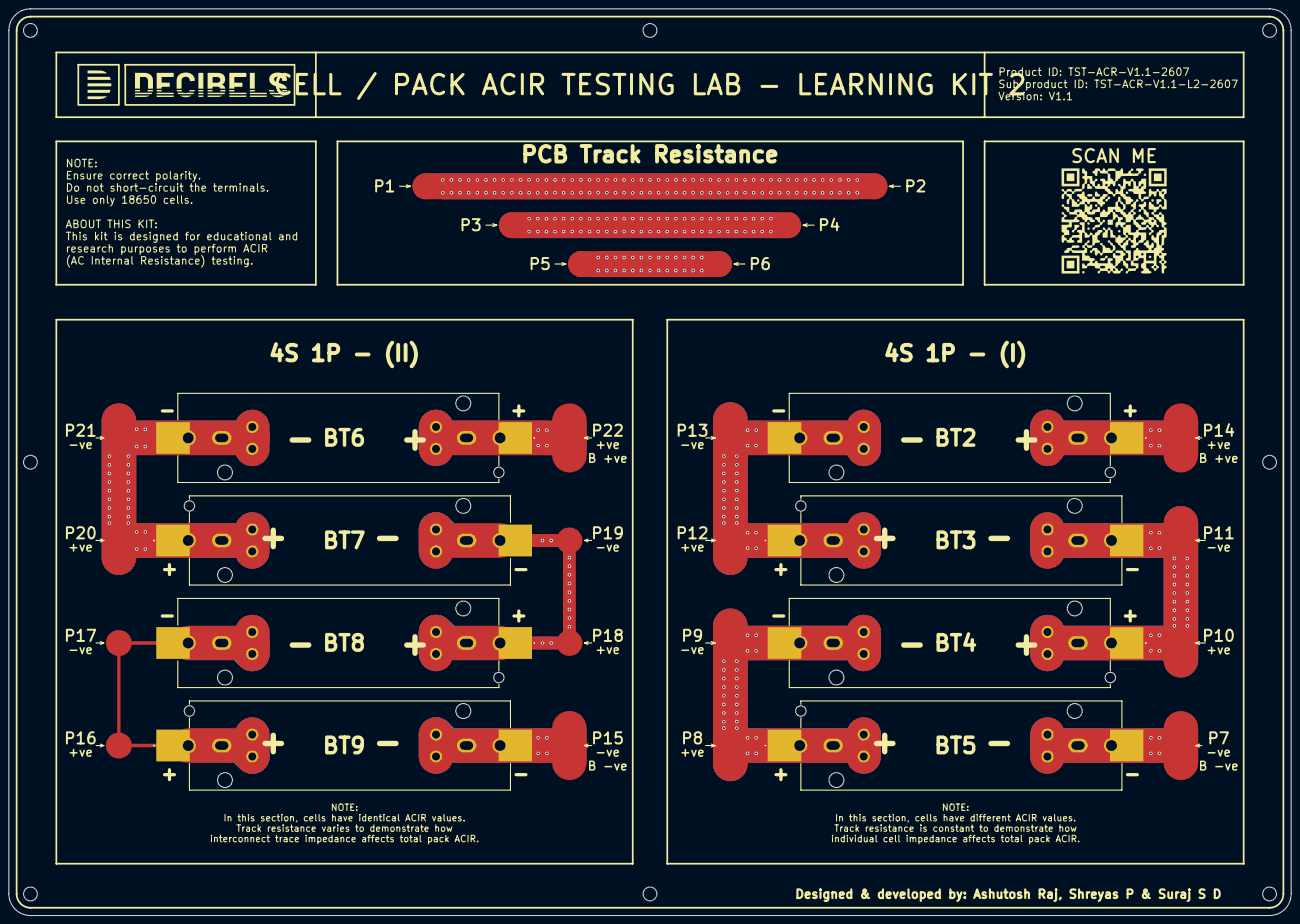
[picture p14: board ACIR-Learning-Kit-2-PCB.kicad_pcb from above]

Board: 2 copper layers, 297.0 x 210.0 mm, 38 parts (0 on the bottom side), 13 nets.

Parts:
BT2, BT3, BT4, BT5, BT6, BT7, BT8, BT9: BH-18650-B5BA008; BH18650B1BA002
H1, H2, H3, H4, H5, H6, H7, H8: MountingHole_M3_Pad; MountingHole_3.2mm_M3
J3: 4S B +ve; TestPoint_Pad_D6.0mm
J4: 4S B -ve; TestPoint_Pad_D6.0mm
J7: 2S 1P +ve; TestPoint_Pad_D6.0mm
J8: 3S 1P +ve; TestPoint_Pad_D6.0mm
J9: 4S 1P +ve; TestPoint_Pad_D6.0mm
J10: 1S 1P +ve; TestPoint_Pad_D6.0mm
J11, J18: 1S 1P -ve; TestPoint_Pad_D6.0mm
J12: 1S 3P +ve; TestPoint_Pad_D6.0mm
J13: 1S 3P -ve; TestPoint_Pad_D6.0mm
J14: 1S 4P +ve; TestPoint_Pad_D6.0mm
J15: 1S 4P -ve; TestPoint_Pad_D6.0mm
J16: 1S 2P +ve; TestPoint_Pad_D6.0mm
J17: 1S 2P -ve; TestPoint_Pad_D6.0mm
J19: 2S 1P -ve; TestPoint_Pad_D6.0mm
J20: 3S 1P -ve; TestPoint_Pad_D6.0mm
P1, P4, P6: 1S 1P -ve; TestPoint_Pad_D6.0mm
P2, P3, P5: 1S 1P +ve; TestPoint_Pad_D6.0mm

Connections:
/4S_B+: BT2.1 (+), J3.1 (Pin_1_1)
/4S_B-: BT5.2 (-), J4.1 (Pin_1_1)
unnamed: BT2.2 (-), BT3.1 (+), J7.1 (Pin_1_1), J18.1 (Pin_1_1)
unnamed: BT3.2 (-), BT4.1 (+), J8.1 (Pin_1_1), J19.1 (Pin_1_1)
unnamed: BT4.2 (-), BT5.1 (+), J9.1 (Pin_1_1), J20.1 (Pin_1_1)
unnamed: BT6.1 (+), J10.1 (Pin_1_1)
unnamed: BT6.2 (-), BT7.1 (+), J11.1 (Pin_1_1), J13.1 (Pin_1_1)
unnamed: BT7.2 (-), BT8.1 (+), J12.1 (Pin_1_1), J14.1 (Pin_1_1)
unnamed: BT8.2 (-), BT9.1 (+), J15.1 (Pin_1_1), J17.1 (Pin_1_1)
unnamed: BT9.2 (-), J16.1 (Pin_1_1)
unnamed: P1.1 (Pin_1_1), P2.1 (Pin_1_1)
unnamed: P3.1 (Pin_1_1), P4.1 (Pin_1_1)
unnamed: P5.1 (Pin_1_1), P6.1 (Pin_1_1)

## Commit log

2026-09-14 Initial commit: ACIR Learning Kit 1 clean project setup
    [ACIR_PCB.kicad_pcb, ACIR_PCB.kicad_sch, ACIR_PCB_BOM.csv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]
2026-09-14 Optimize layout: equalized track ACIR, mirrored B.Cu copper with via stitching, uniform 23.75mm holder spacing, and Kelvin testpoints
    [ACIR_PCB.kicad_pcb]
2026-09-14 Align test points and resolve silkscreen text and arrow collisions in 1S 4P and 4S 1P modules
    [ACIR_PCB.kicad_pcb]
2026-09-14 Align 1S 4P test points horizontally, add Cell 4 test points (J16, J17), and connect pack test points
    [ACIR_PCB.kicad_pcb, ACIR_PCB.kicad_sch]
2026-09-14 Update 1S 4P: 90-degree test points, exact symmetry, circular bare-copper zone with F.Mask aperture, and dense via stitching
    [ACIR_PCB.kicad_pcb]
2026-09-14 Align test points symmetrically, increase via stitching density, and update 4S1P and 1S1P modules
    [ACIR_PCB.kicad_pcb]
2026-09-14 Make PCB production ready: clear silkscreen on copper, add comprehensive test point labels and arrows, and resolve all DRC warnings
    [ACIR_PCB.kicad_pcb]
2026-09-14 Update probing points with knockout badges, PT Sans font, and cell-by-cell +ve/-ve naming
    [ACIR_PCB.kicad_pcb]
2026-09-14 Add and align dedicated test points and bare-copper circular zones for every cell in 4S1P with knockout PT Sans labels
    [ACIR_PCB.kicad_pcb, ACIR_PCB.kicad_sch]
2026-09-14 Upgrade via stitching to ultra-dense 6-column arrays across all power rails and interconnects (1,792 stitched vias)
    [ACIR_PCB.kicad_pcb]
2026-09-14 Enlarge test point labels and knockout badges across all modules for clear eye visibility (1.4mm to 1.6mm font)
    [ACIR_PCB.kicad_pcb]
2026-09-14 Production verification complete: restore 1S 4P and 4S 1P header titles, audit silkscreen clearances, and generate production Gerbers and drill package
    [ACIR_PCB-B_Courtyard.gbr, ACIR_PCB-B_Cu.gbl, ACIR_PCB-B_Fab.gbr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]
2026-09-14 Fix Decibels logo: move left icon box from F.Fab to F.SilkS so both logo boxes are visible on silkscreen
    [ACIR_PCB-B_Courtyard.gbr, ACIR_PCB-B_Cu.gbl, ACIR_PCB-B_Fab.gbr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]
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2026-09-15 test: add test schematics, ERC reports, and verification artifacts for ACIR PCB
    [test_bisect.kicad_sch, test_diag.kicad_sch, test_fix_all.kicad_sch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]
2026-09-16 feat: add test points to PCB layout and generate production and Gerber files
    [ACIR_PCB-B_Cu.gbr, ACIR_PCB-B_Mask.gbr, ACIR_PCB-B_Paste.gbr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]
2026-09-16 refactor: replace through-hole test points with SMD pads in PCB layout
    [ACIR_PCB.kicad_pcb, ACIR_PCB.kicad_sch]
2026-09-16 chore: clean up test artifacts and generate production gerbers and manufacturing files
    [ACIR_PCB-B_Courtyard.gbr, ACIR_PCB-B_Cu.gbl, ACIR_PCB-B_Cu.gbr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]
2026-09-16 chore: generate gerbers and production manufacturing files for PCB layout
    [ACIR_PCB-B_Courtyard.gbr, ACIR_PCB-B_Cu.gbl, ACIR_PCB-B_Fab.gbr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]
2026-09-16 feat: add KiCad schematic, PCB layout, and production gerber files for ACIR Learning Kit 1
    [ACIR-Learning-Kit-1-PCB.kicad_pcb, ACIR-Learning-Kit-1-PCB.kicad_sch, ACIR-Learning-Kit-1-PCB_BOM.csv]
2026-09-16 chore: update PCB design and generate production gerbers and manufacturing files
    [ACIR-Learning-Kit-1-PCB-B_Courtyard.gbr, ACIR-Learning-Kit-1-PCB-B_Cu.gbl, ACIR-Learning-Kit-1-PCB-B_Fab.gbr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]
2026-09-16 docs: add project README and PCB DRC/ERC validation reports
    [ACIR-Learning-Kit-1-PCB-B_Courtyard.gbr, ACIR-Learning-Kit-1-PCB-B_Cu.gbl, ACIR-Learning-Kit-1-PCB-B_Fab.gbr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]
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2026-09-16 feat: initialize ACIR-Learning-Kit-2-PCB project with layout, gerbers, and documentation
    [ACIR-Learning-Kit-2-PCB-B_Courtyard.gbr, ACIR-Learning-Kit-2-PCB-B_Cu.gbl, ACIR-Learning-Kit-2-PCB-B_Fab.gbr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]
2026-09-17 feat: add PCB design files for ACIR Learning Kits 1 and 2
    [ACIR-Learning-Kit-1-PCB.kicad_pcb, ACIR-Learning-Kit-2-PCB.kicad_pcb, ACIR-Learning-Kit-2-PCB.kicad_sch]
2026-09-17 feat: add ACIR Learning Kit 2 PCB design files and production outputs
    [ACIR-Learning-Kit-1-PCB.kicad_pcb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]
2026-09-17 feat: DFM optimization - clean circular probing pads, uniform 2.0mm via pitch, and zero warnings
    [ACIR-Learning-Kit-1-PCB.kicad_sch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]
2026-09-17 feat: synchronize Kit 2 silkscreen with Kit 1, achieve 100% parity, and update production deliverables
    [ACIR-Learning-Kit-2-PCB-B_Courtyard.gbr, ACIR-Learning-Kit-2-PCB-B_Cu.gbl, ACIR-Learning-Kit-2-PCB-B_Fab.gbr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]
2026-09-17 feat: make PCB Track Resistance equidistant, center-aligned, and symmetric with arrows for all probe points
    [ACIR-Learning-Kit-2-PCB-B_Courtyard.gbr, ACIR-Learning-Kit-2-PCB-B_Cu.gbl, ACIR-Learning-Kit-2-PCB-B_Fab.gbr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]
2026-09-17 Restore battery holder solder pads and knockout polarity markings on Kit 2
    [ACIR-Learning-Kit-2-PCB-B_Courtyard.gbr, ACIR-Learning-Kit-2-PCB-B_Cu.gbl, ACIR-Learning-Kit-2-PCB-B_Fab.gbr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]
2026-09-17 Standardize P18/P12 copper caps to match P10/P3 and add vias in 4S 1P (II)
    [ACIR-Learning-Kit-2-PCB-B_Courtyard.gbr, ACIR-Learning-Kit-2-PCB-B_Cu.gbl, ACIR-Learning-Kit-2-PCB-B_Fab.gbr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]
2026-09-17 Remove vias overlapping battery holder solder pads across all cells
    [ACIR-Learning-Kit-2-PCB-B_Courtyard.gbr, ACIR-Learning-Kit-2-PCB-B_Cu.gbl, ACIR-Learning-Kit-2-PCB-B_Fab.gbr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]
2026-09-18 chore: add production files for ACIR Learning Kit 2 PCB v2.0
    [bom.csv, designators.csv, positions.csv]
2026-09-18 feat: add PCB design files, gerbers, and production outputs for ACIR Learning Kits 1 and 2
    [ACIR-Learning-Kit-1-PCB-B_Courtyard.gbr, ACIR-Learning-Kit-1-PCB-B_Cu.gbl, ACIR-Learning-Kit-1-PCB-B_Fab.gbr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]
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2026-09-18 fix: restore through-hole custom pads on all 180-degree rotated battery holders in Kits 1 and 2
    [ACIR-Learning-Kit-1-PCB-B_Courtyard.gbr, ACIR-Learning-Kit-1-PCB-B_Cu.gbl, ACIR-Learning-Kit-1-PCB-B_Fab.gbr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]
2026-09-18 feat: add 3D STEP models for 18650 battery holders and regenerate 3D renders
    [ACIR-Learning-Kit-1-PCB-B_Courtyard.gbr, ACIR-Learning-Kit-1-PCB-B_Cu.gbl, ACIR-Learning-Kit-1-PCB-B_Fab.gbr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]
